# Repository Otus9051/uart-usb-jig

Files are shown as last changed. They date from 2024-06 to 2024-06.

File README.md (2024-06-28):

# MicroUSB to TTL to USB converter
## Should work with almost any Samsung device

- Connectors:
    - Micro USB B Male
    - USB A 2.0 Female
 
- Utitlizes CP2102N as the Serial to USB convertor
- ID pin of Micro USB B Male is connected to 619K Ohm Resistor
- 619K Ohm Resistance triggers Samsung MUIC to switch to USB UART mode
Samsung Universal MUIC Code Comment Block
- LCSC Part Numbers included in Bill of Materials
- Pulls 5V from USB A, Micro USB B gets 3.3V from CP2102 VDD (refer documentation)

PCB 3D Side Profile
PCB Front Render
PCB
Schematics

P.S.: This is my first try at making a PCB, please let me know any issues if you come across any

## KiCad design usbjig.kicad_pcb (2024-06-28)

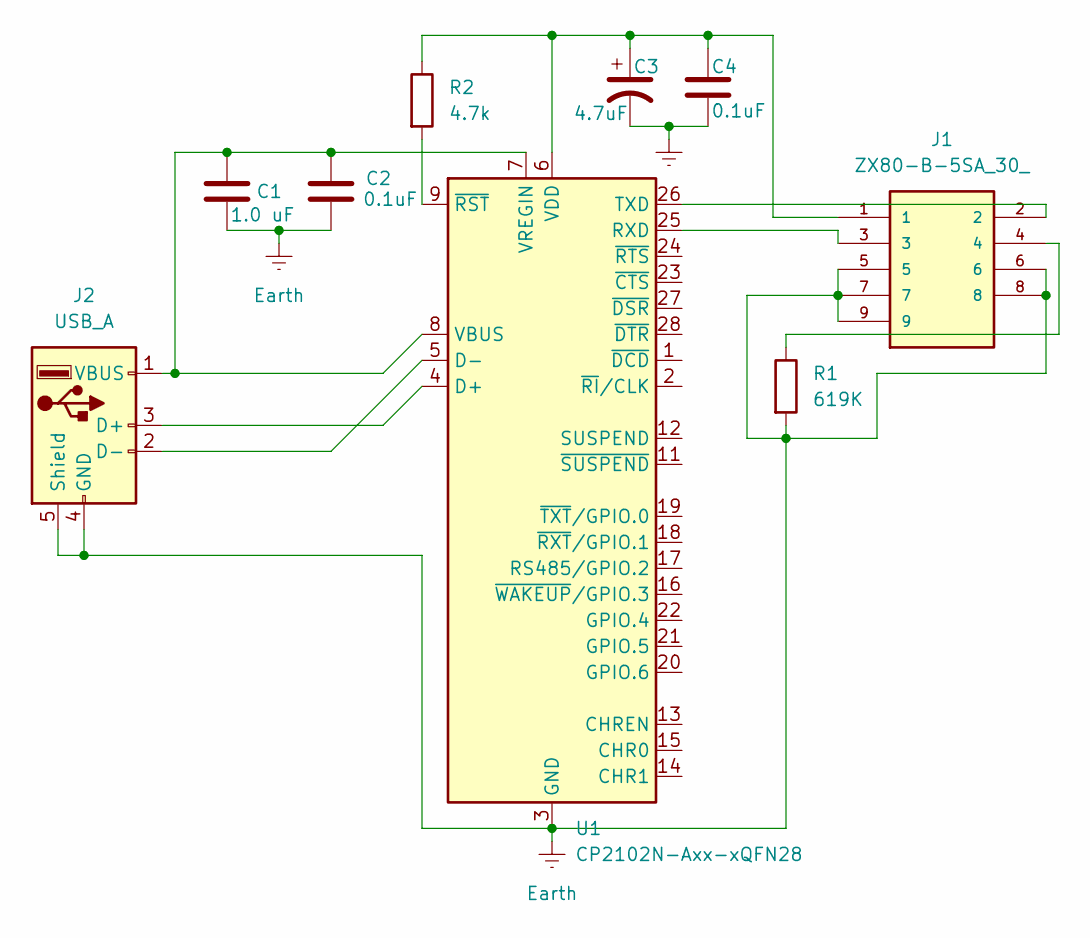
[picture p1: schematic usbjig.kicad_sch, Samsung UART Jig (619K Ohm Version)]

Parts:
C1: 1.0 uF; C_0201_0603Metric; LCSC C1848
C2, C4: 0.1uF; CP_Elec_4x5.4; LCSC C271438
C3: 4.7uF; CP_Elec_4x5.4; LCSC C271399
J1: ZX80-B-5SA_30_; ZX80B5SA30; LCSC C598212
J2: USB_A; USB_A_Molex_67643_Horizontal; LCSC C293351
R1: 619K; R_0201_0603Metric; LCSC C3015991
R2: 4.7k; R_0201_0603Metric
U1: CP2102N-Axx-xQFN28; QFN-28-1EP_5x5mm_P0.5mm_EP3.35x3.35mm; LCSC C964632

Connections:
Earth: C1.2, C2.2, C3.2, C4.2, J1.5, J1.6, J1.7, J1.8, J1.9, J2.4 (GND), J2.5 (Shield), R1.2, U1.3 (GND), U1.29 (GND)
unnamed: J1.4, R1.1
unnamed: J2.3 (D+), U1.4 (D+)
unnamed: J2.2 (D-), U1.5 (D-)
unnamed: C1.1, C2.1, J2.1 (VBUS), U1.7 (VREGIN), U1.8 (VBUS)
unnamed: J1.3, U1.25 (RXD)
unnamed: J1.2, U1.26 (TXD)
unnamed: C3.1, C4.1, J1.1, R2.1, U1.6 (VDD)
unnamed: R2.2, U1.9 (~RST)

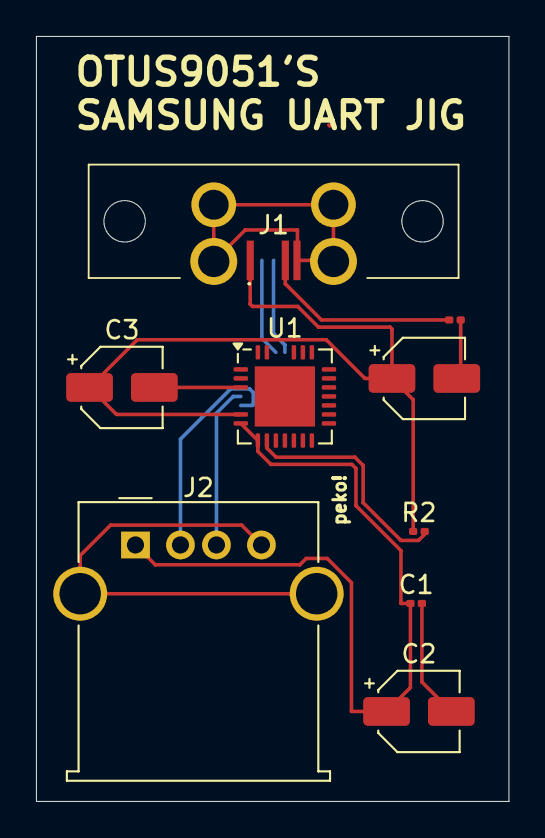
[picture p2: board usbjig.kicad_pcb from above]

Board: 2 copper layers, 26.2 x 42.5 mm, 9 parts (0 on the bottom side), 9 nets.
